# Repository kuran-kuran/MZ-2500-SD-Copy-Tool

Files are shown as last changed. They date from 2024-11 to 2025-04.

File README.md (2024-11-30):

# SHARP MZ-2500 SD Copy Tool

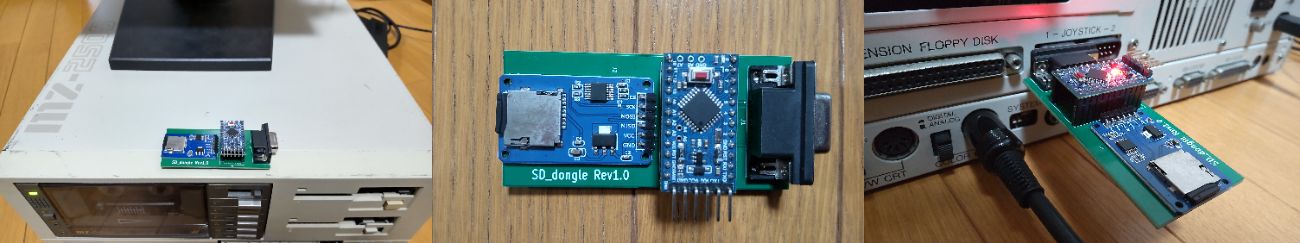
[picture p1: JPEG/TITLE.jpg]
MZ-2500 SD Copy Tool


　MZ-2500のジョイスティックポート1に挿したSD-dongleのSD-CARDとMZ-2500のFD、HDD間でOBT、BTX、BSDファイルを相互にコピーできるツールです。

　Windows等のツールで作成したMZ-2500用の機械語及びBASICプログラムをMZ-2500のFD、HDDにコピー、MZ-2500のFD、HDDのファイルを取り出してWindows等のツールで修正し、MZ-2500のFD、HDDに戻す等が簡単にできます。

## 回路図
　KiCadフォルダ内のSD_dongle.pdfを参照してください。

[回路図](https://github.com/yanataka60/MZ-2500-SD-Copy-Tool/blob/main/Kicad/SD_dongle.pdf)

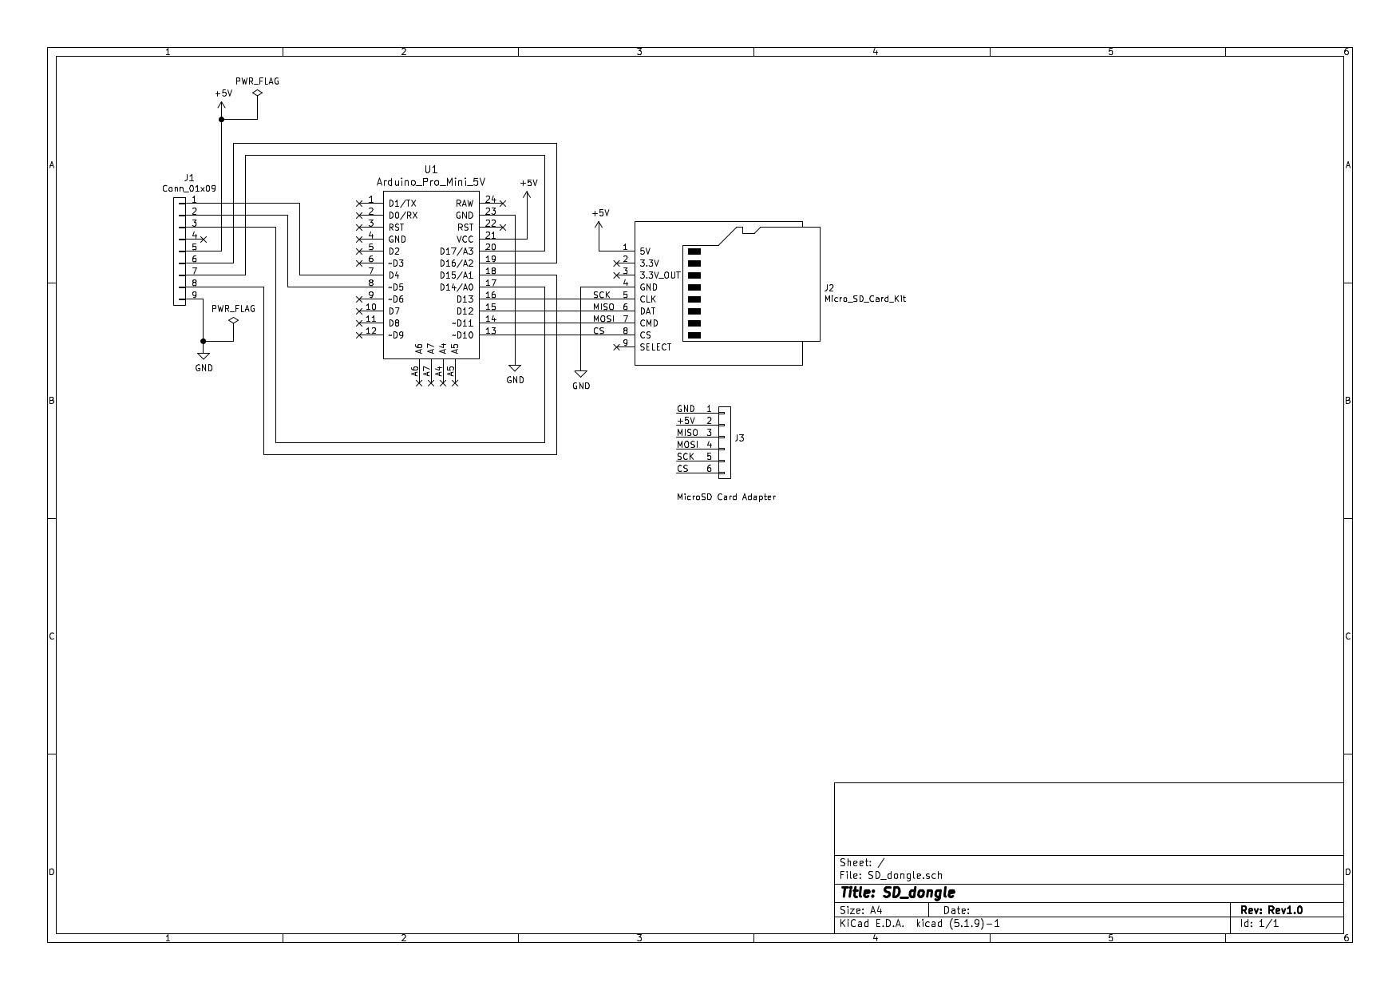
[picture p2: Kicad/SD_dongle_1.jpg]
SD_dongle


|番号|品名|数量|備考|
| --- | --- | --- | --- |
|J1|D-SUBコネクター9Pメス|1|マルツ 3223DB9RS1S2等|
||J2、J3のいずれか|||
|J2|Micro_SD_Card_Kit|1|秋月電子通商 AE-microSD-LLCNV (注1)|
|J3|MicroSD Card Adapter|1|Arduino等に使われる5V電源に対応したもの(注2)|
|U1|Arduino_Pro_Mini_5V|1|Atmega328版を使用 168版は不可。(注3)|
||ピンソケット(任意)|12Pin×2|Arduino_Pro_Miniを取り外し可能としたい場合に調達します 秋月電子通商 FHU-1x42SGなど|

### 注1)秋月電子通商　AE-microSD-LLCNVのJ1ジャンパはショートしてください。

### 注2)MicroSD Card Adapterを使う場合

J3に取り付けます。

MicroSD Card Adapterについているピンヘッダを除去してハンダ付けするのが一番確実ですが、J2の穴にMicroSD Card Adapterをぴったりと押しつけ、裏から多めにハンダを流し込むことでハンダ付けをする方法もあります。なお、この方法の時にはしっかりハンダ付けが出来たかテスターで導通を確認しておいた方が安心です。

ハンダ付けに自信のない方はJ1の秋月電子通商　AE-microSD-LLCNVをお使いください。AE-microSD-LLCNVならパワーLED、アクセスLEDが付いています。

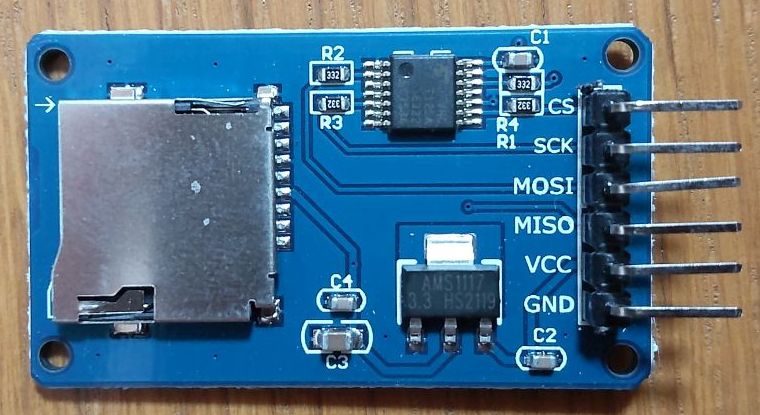
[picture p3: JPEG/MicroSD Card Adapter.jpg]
MicroSD Card Adapter1


### 注3)MZ-2500 SD Copy Tool用SD-DongleではArduino Pro MiniのA4、A5ピンは使用しません。

## Arduinoへの書込み
　Arduino IDEを使ってArduinoフォルダSD_dongleフォルダ内SD_dongle.inoを書き込みます。

　SdFatライブラリを使用しているのでArduino IDEメニューのライブラリの管理からライブラリマネージャを立ち上げて「SdFat」をインストールしてください。

　「SdFat」で検索すれば見つかります。「SdFat」と「SdFat - Adafruit Fork」が見つかりますが「SdFat」のほうを使っています。

## MZ-2500用Copy Toolプログラム
　MZ-2500のFD、HDD、FDDエミュレータ用FDイメージにOBTファイルを転送する手段がある方はSD_TRANSフォルダ内のSD_TRANS.binを転送してください。

　転送する手段の無い方はBASIC-S25又はBASIC-M25からモニタMコマンドでSD_LOADERフォルダ内のSD_LOADER.binの内容を入力します。

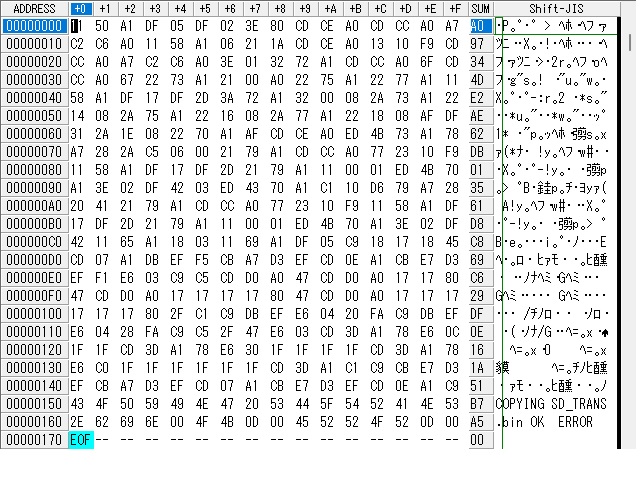
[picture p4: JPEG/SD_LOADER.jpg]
SD_LOADER


　入力間違いが無いことを確認し、SコマンドでSD_LOADER.bin等の名前を付けてセーブしてください。

　　*S A000 A16F A000:SD_LOADER.bin

　次にSD_TRANSフォルダ内のSD_TRANS.binをSD-CARDにコピーし、次のコマンドを実行します。

### (BASIC-M25)

　clear &HA000

　bload "SD_LOADER.bin"

　FD、HDDのカレントディレクトリをSD_TRANS.bin転送先ディレクトリに変更

　call &HA000

### (BASIC-S25)

　limit &HA000

　load "SD_LOADER.bin"

　FD、HDDのカレントディレクトリをSD_TRANS.bin転送先ディレクトリに変更

　call &HA000

　問題が無ければ「OK」と表示されて終了し、SD_TRANS.binがFD、HDDのカレントディレクトリに転送されているはずです。

## SD-CARD
　出来れば8GB以下のSDカードを用意してください。

　ArduinoのSdFatライブラリは、SD規格(最大2GB)、SDHC規格(2GB～32GB)に対応していますが、SDXC規格(32GB～2TB)には対応していません。

　また、SDHC規格のSDカードであっても32GB、16GBは相性により動作しないものがあるようです。

　FAT16又はFAT32が認識できます。NTFSは認識できません。

## 操作方法
　clear又はlimitで機械語領域を確保してからbload又はloadコマンドでSD_TRANS.binをロードします。

　必要があればFD又はHDDのカレントディレクトリを変更しておきます。

　SD-Dongleをジョイスティックポート1に挿します。

　call &HA000でCopy Toolを実行します。

　SD-CARDのファイル名は拡張子も含めて32文字まで、ただし漢字、半角カタカナ、及び一部の記号はArduinoが認識しないので使えません。パソコンでファイル名を付けるときはアルファベット、数字および空白でファイル名をつけてください。

　また、SD-CARDからFD、HDDにコピーされたファイルのファイル名は先頭16文字までとなります。

　Copy Toolが起動したらまず処理の選択をします。

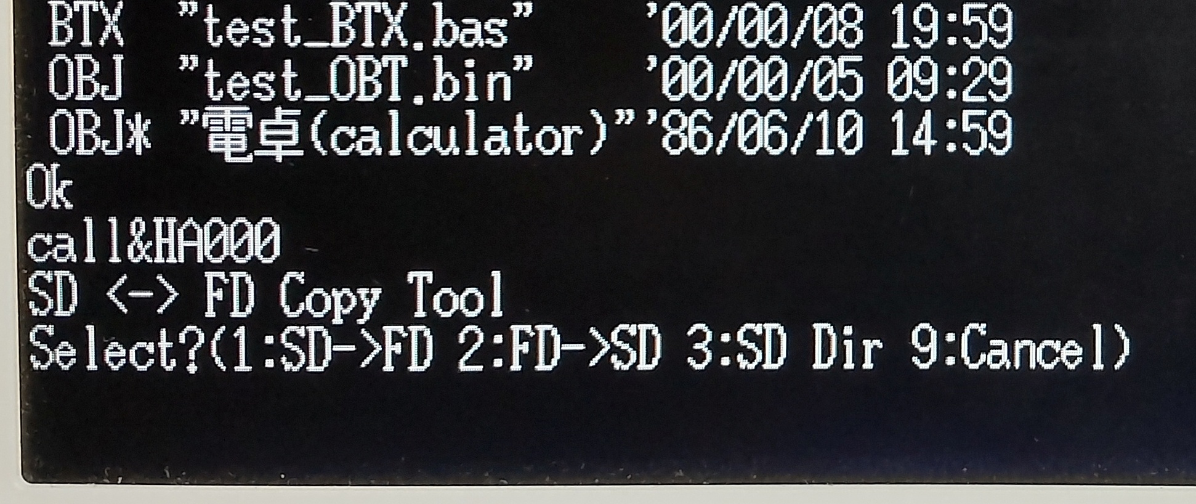
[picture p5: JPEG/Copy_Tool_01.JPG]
Copy_Tool_01


### 1 SD -> FD
　SD-CARDのファイルをFD、HDDにコピーします。

　次にSD-CARDのファイル名を指定します。

　大文字、小文字は区別されるので大文字、小文字も正確に入力してください。

　FD、HDDにはSD-CARDのファイル名のままコピーされますが、16文字を超えた分は切り捨てられます。

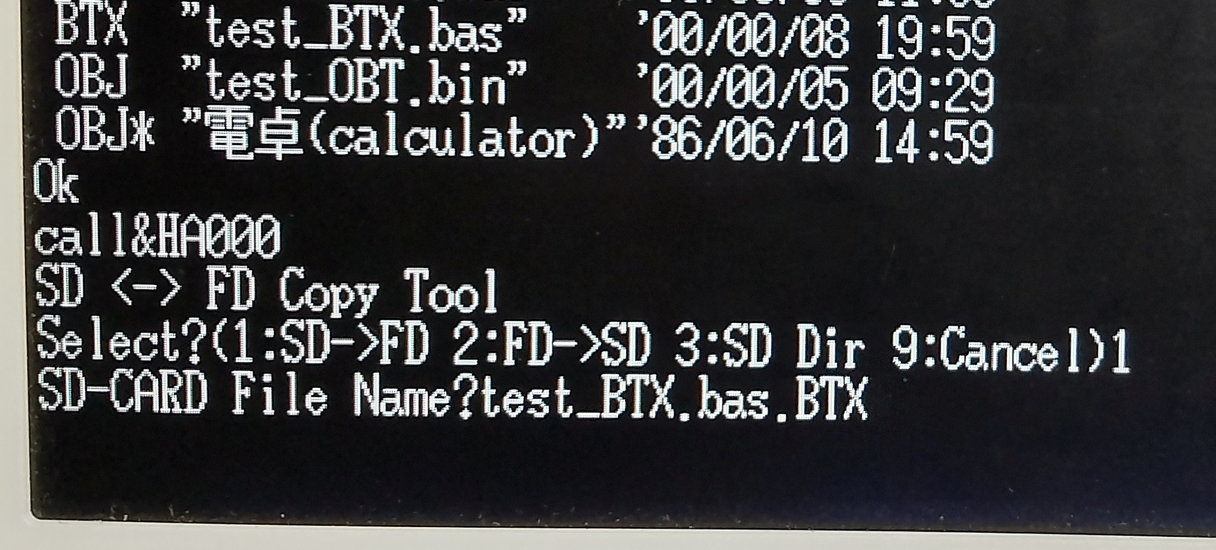
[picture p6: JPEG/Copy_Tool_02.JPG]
Copy_Tool_02


　ファイルモードを指定します。SD-CARDのファイルにはファイルモード等の情報が含まれていないため指定する必要があります。

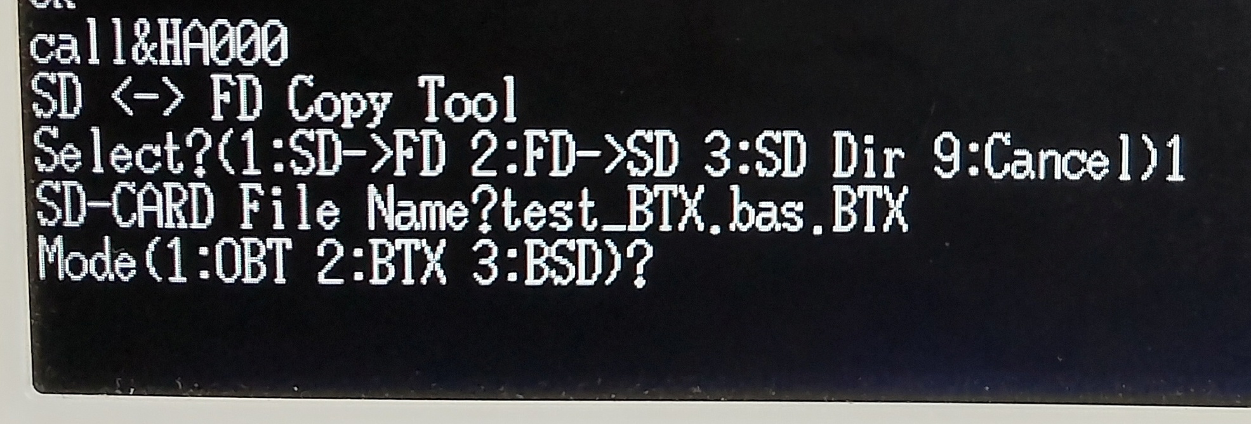
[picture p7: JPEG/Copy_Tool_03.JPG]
Copy_Tool_03


　実際のファイルモードと指定したファイルモードが間違っていてもコピーは正常終了しますが、MZ-2500のBASICからは期待した動作が出来なくなりますので削除してください。

#### 1 OBT
　SD-CARDのファイルには先頭アドレス、実行アドレスの情報が含まれていないため指定する必要があります。

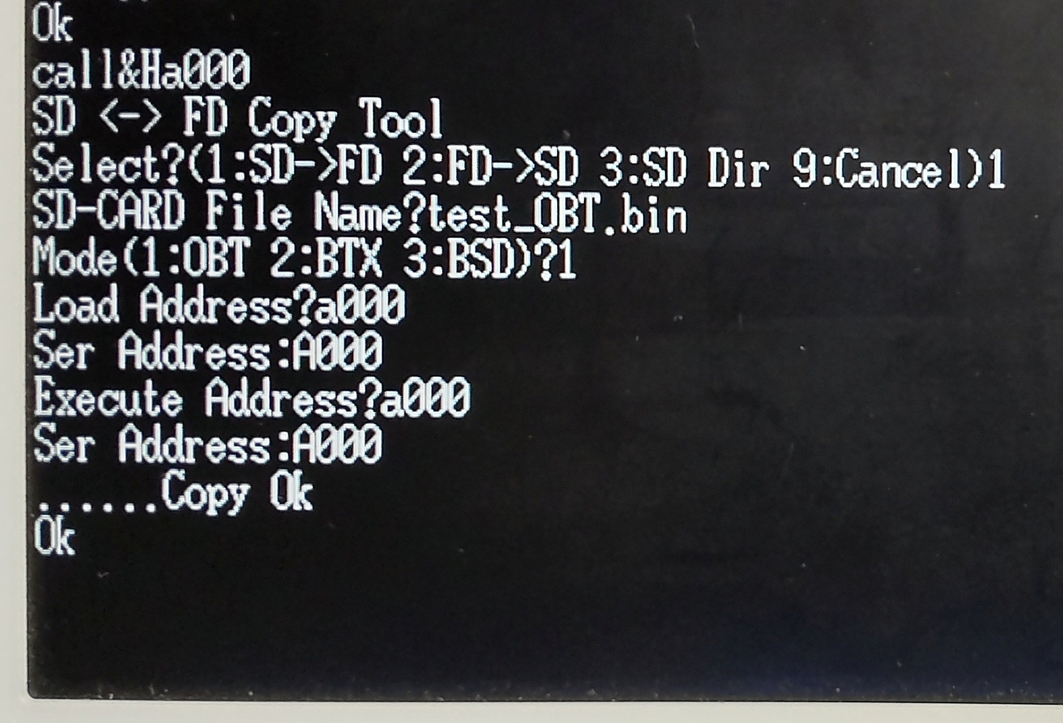
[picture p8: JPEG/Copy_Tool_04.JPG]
Copy_Tool_04


#### 2 BXT
　ファイルモードを指定するだけでコピーが始まります。

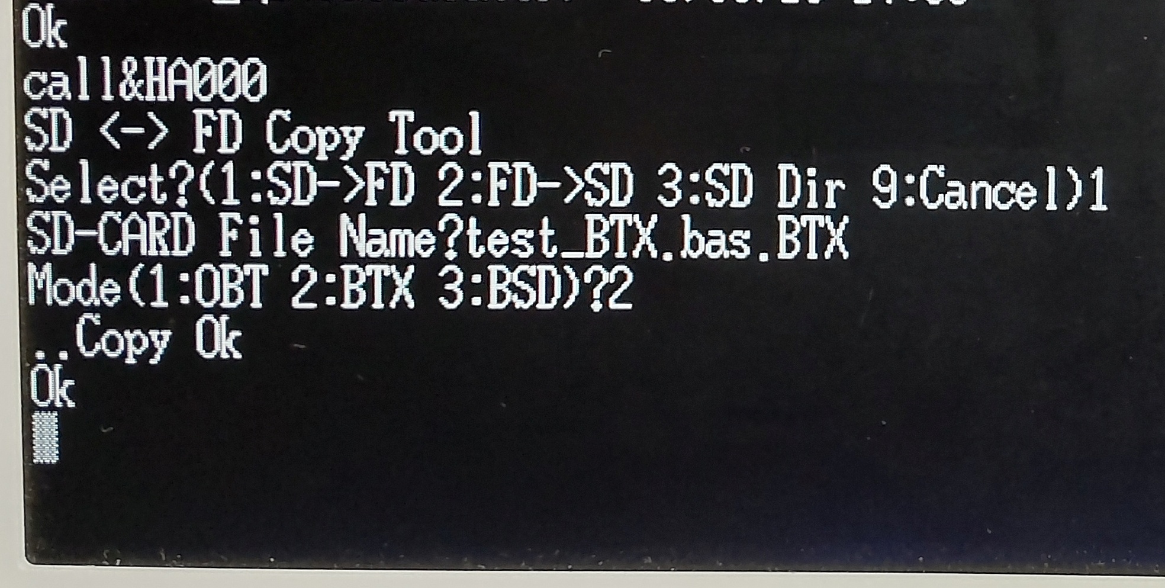
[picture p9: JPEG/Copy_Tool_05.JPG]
Copy_Tool_05


#### 3 BSD
　ファイルモードを指定するだけでコピーが始まります。

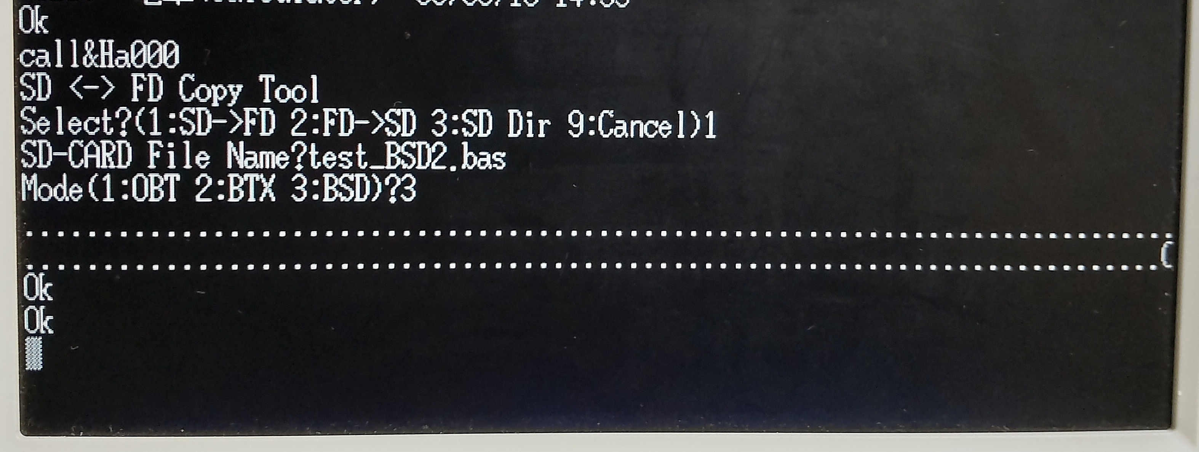
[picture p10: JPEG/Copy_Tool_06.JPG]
Copy_Tool_06


　BSDファイルとはテキストファイルであり、Windows等のテキストエディタでBASICのプログラムとして入力することも可能です。

　ただし、改行コードは0Dhのみ(Windowsのテキストの改行コードは通常0Dh,0Ah)、漢字コードはSHIFTJISで作成してください。

## 注意!!
　SD-CARDからコピーされるファイル名のファイルがコピー先のFD、HDD上に既にある場合、エラー終了します。

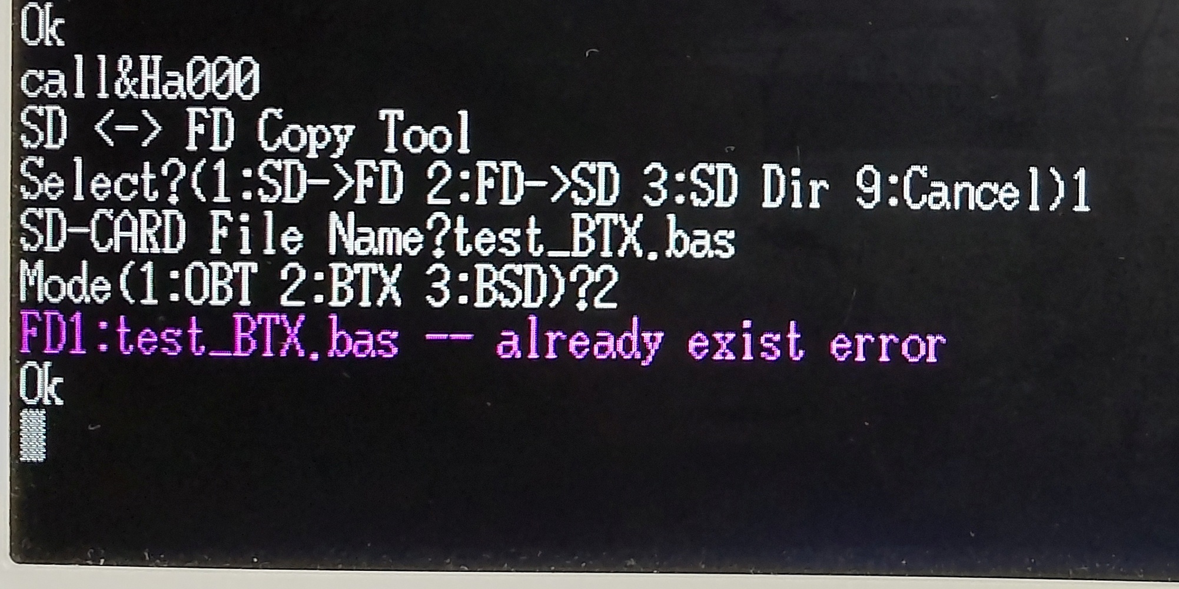
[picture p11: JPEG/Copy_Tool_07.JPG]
Copy_Tool_07


　この「already exist error」で中止されたことをArduinoは認識できないため転送処理が中途半端なまま待機状態となっており、次にCopy Toolが起動されても正常に処理できません。

## 　SD-Dongleを挿し直すことで正常に処理できるよう復旧するので、もう一度Copy Toolを起動する前に必ずSD-Dongleを挿し直してください。

　FD、HDD上に既にあるファイルもCopy Tool起動前には削除してください。

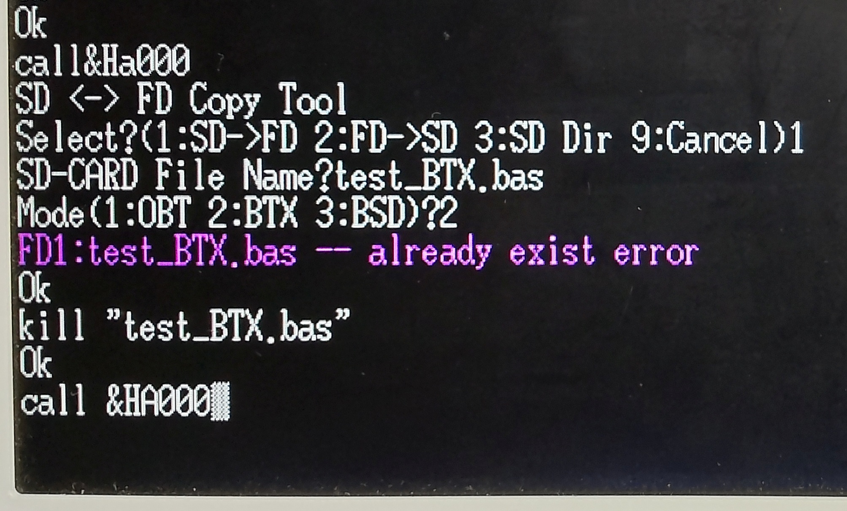
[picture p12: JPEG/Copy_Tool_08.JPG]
Copy_Tool_08


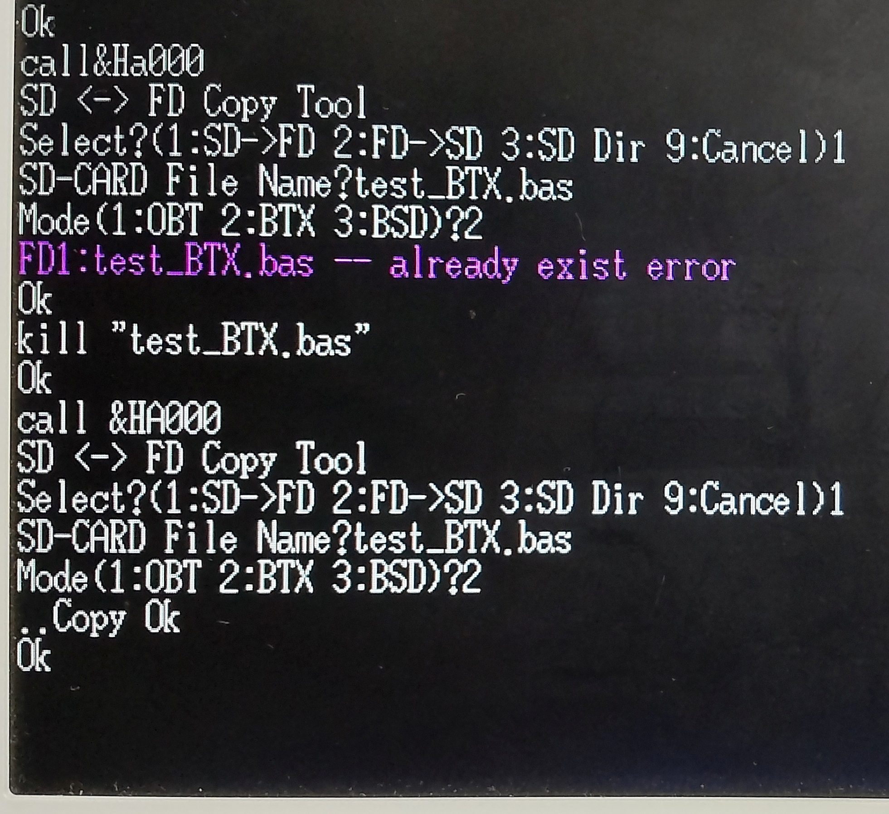
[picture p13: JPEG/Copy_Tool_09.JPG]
Copy_Tool_09


### 2 FD -> SD
　FD、HDDのファイルをSD-CARDにコピーします。

　FD、HDDのファイル名を指定します。

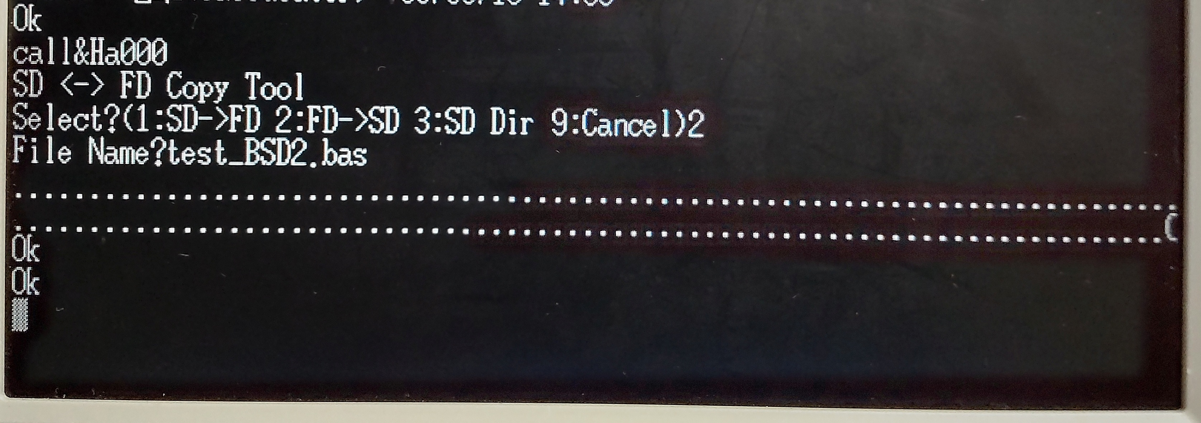
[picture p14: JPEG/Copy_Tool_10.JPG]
Copy_Tool_10


　SD-CARDにコピーされるファイルのファイル名にはFD、HDD上のファイル情報に基づき、拡張子及び先頭アドレス、実行アドレスが付加されます。

　　[OBTファイル] test.OBJ -> test.OBJ_A000_A000.OBT

　　[BTXファイル] test.m25 -> test.m25.BTX

　　[BSDファイル] test     -> test.BSD

### 3 SD DIR
　SD-CARDのルートディレクトリにあるファイル一覧からファイルを選択することでSD-CARDのファイルをFD、HDDにコピーできます。

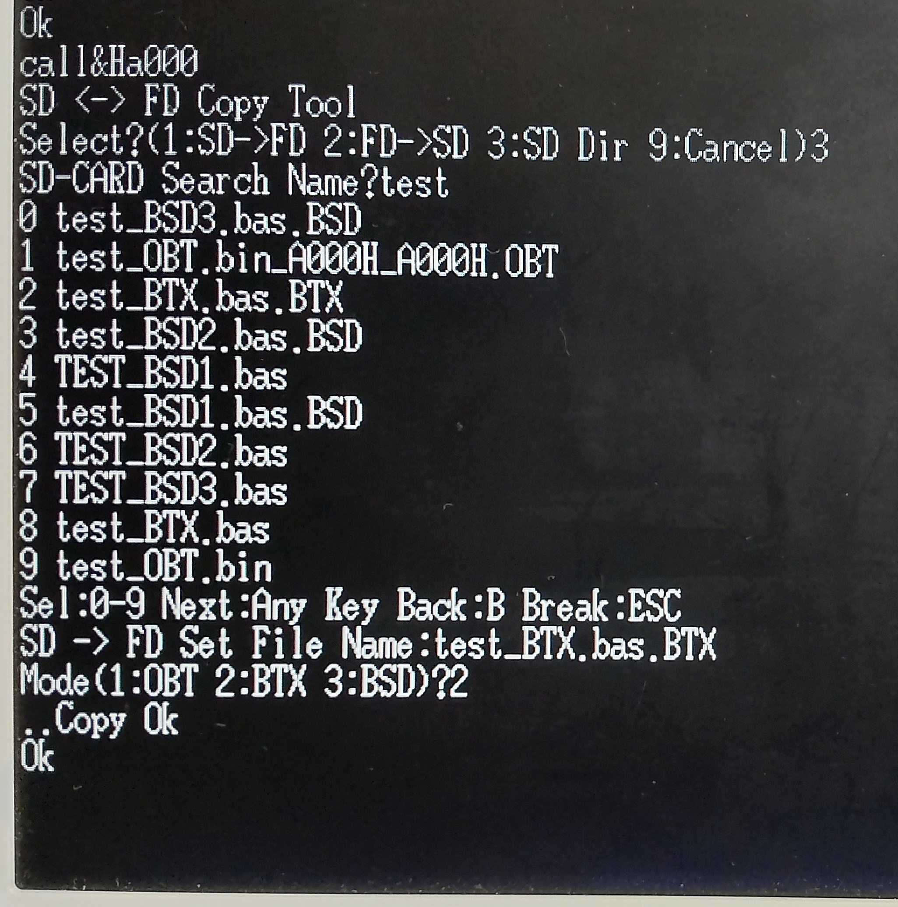
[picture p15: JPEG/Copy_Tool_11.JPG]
Copy_Tool_11


　「SD-CARD Search Name?」と聞いてくるので文字列を何も指定せずにENTERキーのみとするとSD-CARDルートディレクトリにあるファイルの一覧を表示します。

　文字列を指定するとSD-CARDルートディレクトリにあるその文字列から始まるファイルの一覧を表示します。

　10件表示したところで指示待ちになるので打ち切るならESCキー、Bキーで前の10件に戻ります。それ以外のキーで次の10件を表示します。

　行頭に0から9の数字を付加して表示してあるのでコピーしたいファイルの頭についている数字を入力するとコピー処理に移行します。

　検索する文字列は大文字、小文字の区別はありません。大文字、小文字のどちらで入力しても大丈夫です。

　表示される順番は、登録順となりファイル名アルファベッド順などのソートした順で表示することはできません。

## 追記
2024.11.30　Arduinoプログラムに安定性の向上を追加

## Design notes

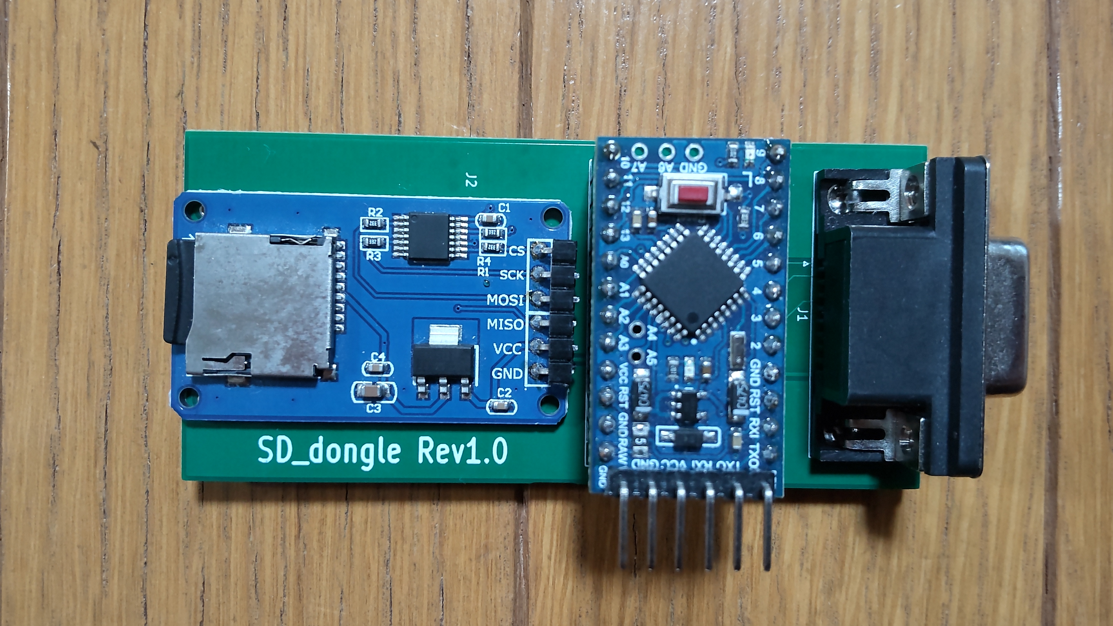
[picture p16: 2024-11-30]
JPEG/SD_dongle.JPG

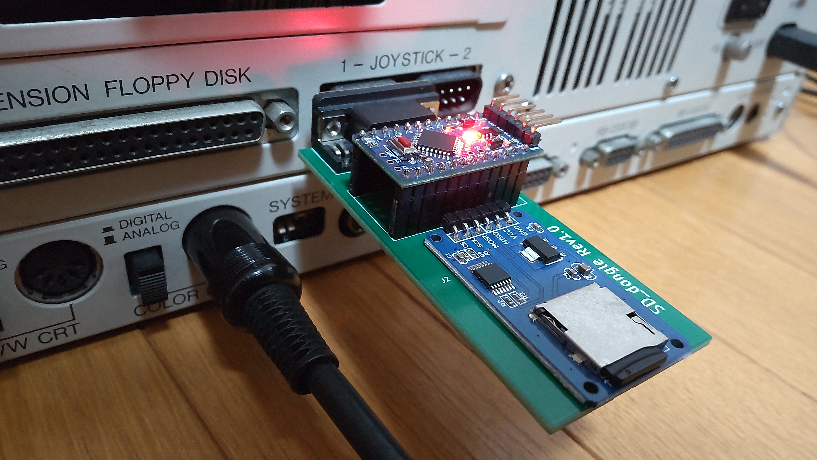
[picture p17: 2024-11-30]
JPEG/MZ-2500(2).JPG

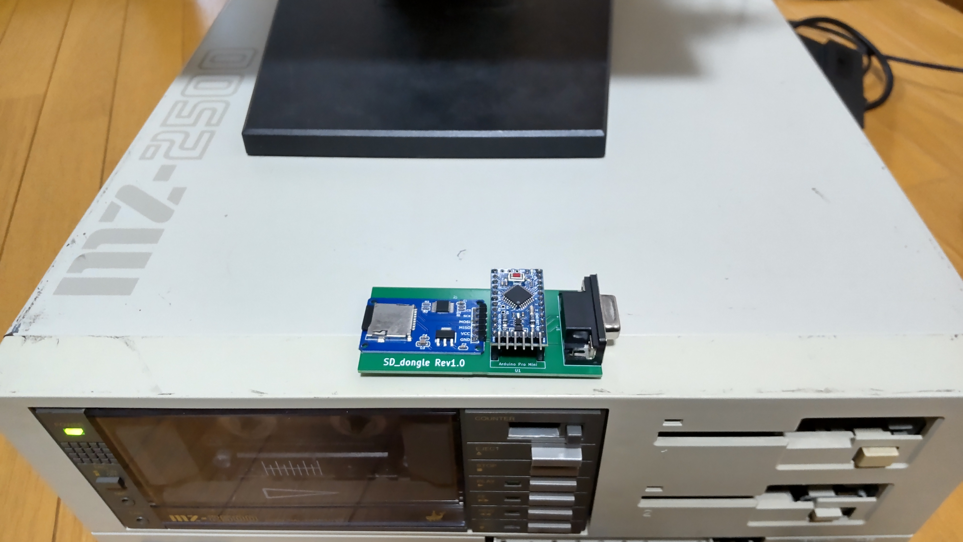
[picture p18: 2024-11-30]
JPEG/MZ-2500(1).JPG

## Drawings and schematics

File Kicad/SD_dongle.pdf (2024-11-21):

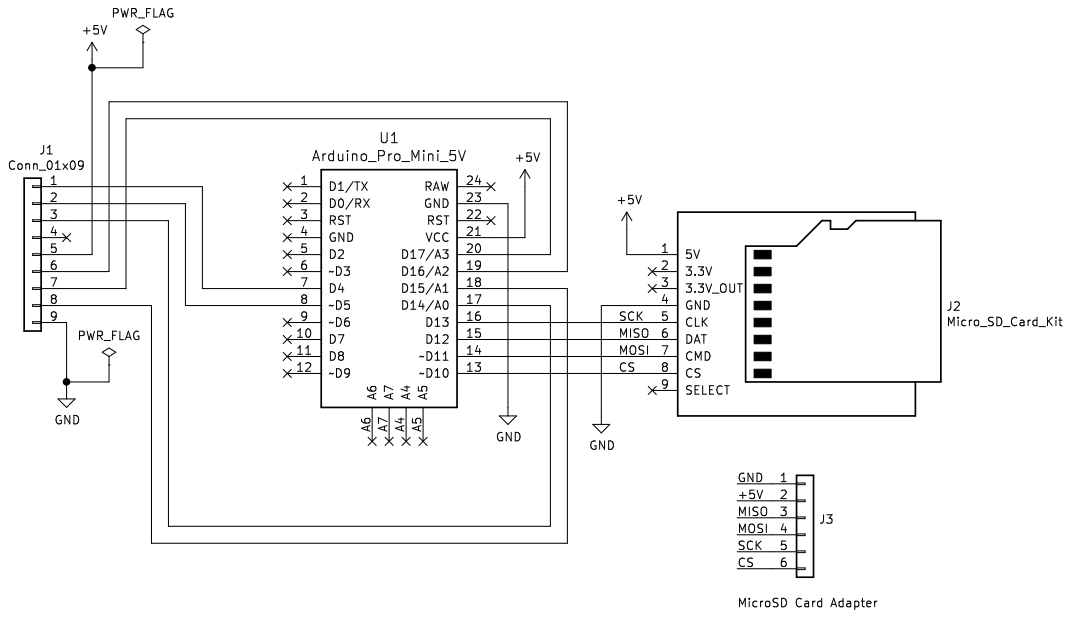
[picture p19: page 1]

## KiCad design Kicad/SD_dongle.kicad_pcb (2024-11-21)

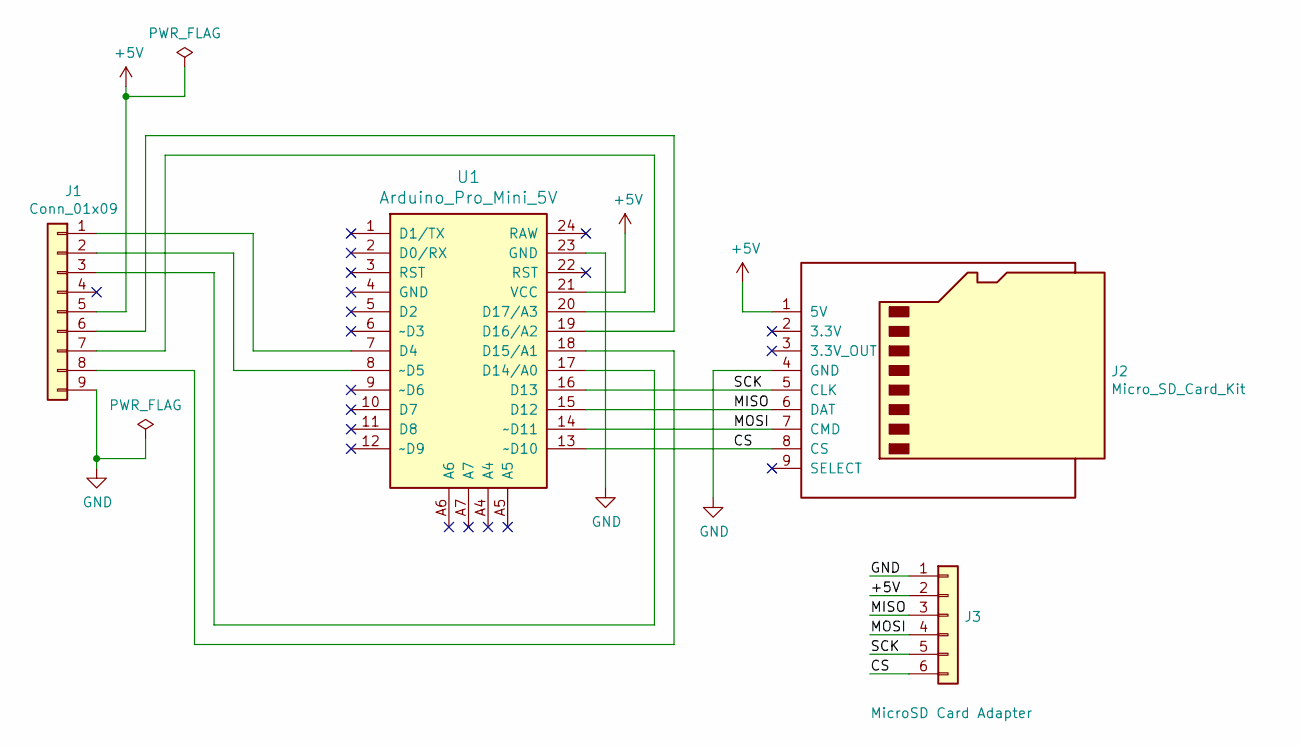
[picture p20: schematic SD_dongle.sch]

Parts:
J1: Conn_01x09; DSUB-9_Female_Horizontal_P2.77x2.84mm_EdgePinOffset7.70mm_H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
J2: Micro_SD_Card_Kit; AE-microSD-LLCNV
J3: MicroSD Card Adapter; PinSocket_1x06_P2.54mm_Vertical
U1: Arduino_Pro_Mini_5V; Arduino_Pro_Mini

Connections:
+5V: J1.5, J2.1 (5V), J3.2, U1.21 (VCC)
/CS: J2.8 (CS), J3.6, U1.13 (~~D10)
/MISO: J2.6 (DAT), J3.3, U1.15 (D12)
/MOSI: J2.7 (CMD), J3.4, U1.14 (~~D11)
/SCK: J2.5 (CLK), J3.5, U1.16 (D13)
GND: J1.9, J2.4 (GND), J3.1, U1.23 (GND)
unnamed: J1.1, U1.7 (D4)
unnamed: J1.2, U1.8 (~~D5)
unnamed: J1.3, U1.17 (D14/A0)
unnamed: J1.6, U1.19 (D16/A2)
unnamed: J1.7, U1.20 (D17/A3)
unnamed: J1.8, U1.18 (D15/A1)

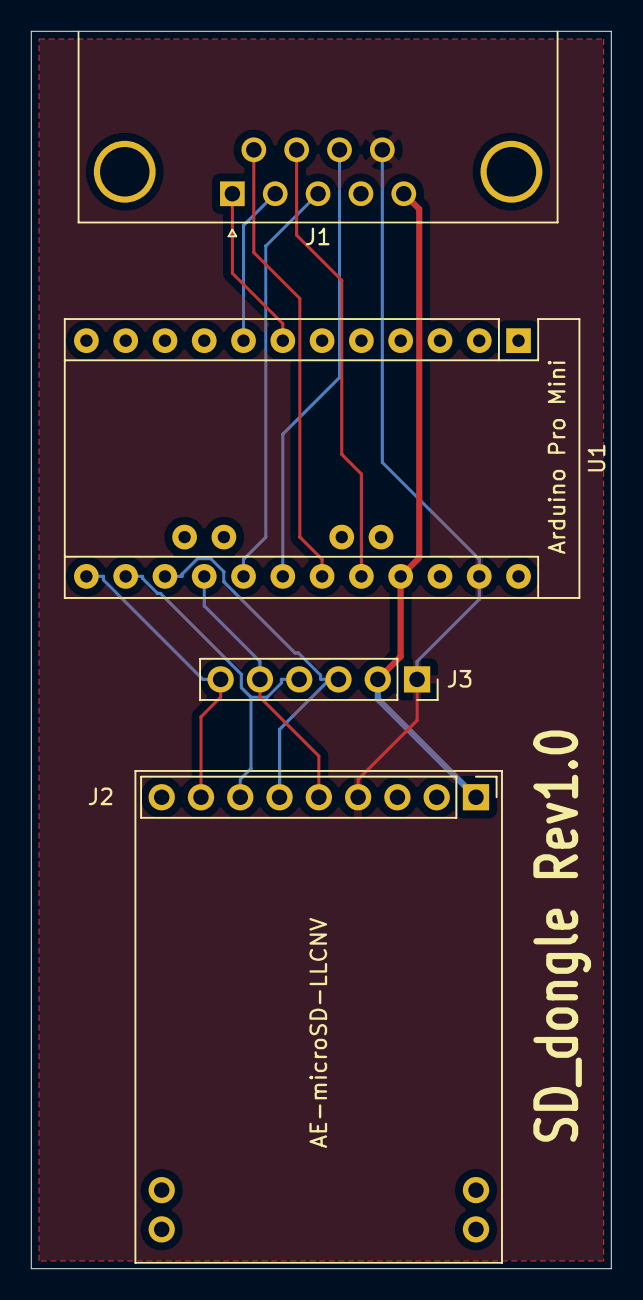
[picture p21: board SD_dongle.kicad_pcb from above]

Board: 2 copper layers, 37.5 x 80.0 mm, 4 parts (0 on the bottom side), 12 nets.

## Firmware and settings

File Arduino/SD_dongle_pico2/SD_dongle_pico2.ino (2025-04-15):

// 2024.11.30 INPUT_PULLUPに修正
// 2024.12.24 RaspberryPI Picoでビルドできるようにした
// 2025.04.16 RaspberryPI Pico2でビルドできるようにした
//
// Joypad  Arduino       Pico
// 1 ----- 4(PB2)  ----- 1
// 2 ----- 5(PB3)  ----- 2
// 3 ----- 14(GLG) ----- 3
// 4 ----- NC      ----- NC
// 5 ----- +5V     ----- VBUS
// 6 ----- 16(PA0) ----- 4
// 7 ----- 17(PA1) ----- 5
// 8 ----- 15(CHK) ----- 0
// 9 ----- GND     ----- GND
//
#include <SPI.h>
#include <SD.h>
//SdFat SD;
char f_name[40];
char c_name[40];
char buf1[10],buf2[10];
char sdir[10][40];
File file;
unsigned long f_length,f_length2,f_length1;
#define CABLESELECTPIN  (17)
#define CHKPIN          (0)
#define PB2PIN          (1)
#define PB3PIN          (2)
#define FLGPIN          (3)
#define PA0PIN          (4)
#define PA1PIN          (5)
// ファイル名は、ロングファイルネーム形式対応
boolean eflg;

void sdinit(void){
  // SD初期化
  if( !SD.begin(CABLESELECTPIN,8) )
  {
////    Serial.println("Failed : SD.begin");
    eflg = true;
  } else {
////    Serial.println("OK : SD.begin");
    eflg = false;
  }
////    Serial.println("START");
}

void setup(){
////  Serial.begin(9600);
// CS=pin10
// pin10 output

  pinMode(CABLESELECTPIN,OUTPUT);
  pinMode( CHKPIN,INPUT);  //CHK
  pinMode( PB2PIN,OUTPUT); //送信データ
  pinMode( PB3PIN,OUTPUT); //送信データ
  pinMode( FLGPIN,OUTPUT); //FLG

  pinMode( PA0PIN,INPUT_PULLUP); //受信データ
  pinMode( PA1PIN,INPUT_PULLUP); //受信データ

  pinMode(LED_BUILTIN, OUTPUT);
  digitalWrite(LED_BUILTIN, HIGH); // LED点灯

  digitalWrite(PB2PIN,LOW);
  digitalWrite(PB3PIN,LOW);
  digitalWrite(FLGPIN,LOW);

  sdinit();
}

//2BIT受信
byte rcv2bit(void){
//LOWになるまでループ
  while(digitalRead(CHKPIN) != LOW){
  }
//受信
  byte j_data = digitalRead(PA0PIN)+digitalRead(PA1PIN)*2;
//FLGをセット
  digitalWrite(FLGPIN,LOW);
//HIGHになるまでループ
  while(digitalRead(CHKPIN) == LOW){
  }
//FLGをリセット
  digitalWrite(FLGPIN,HIGH);
  return(j_data);
}

//1BYTE受信
byte rcv1byte(void){
  byte i_data = 0;
  i_data=rcv2bit();
  i_data=i_data+rcv2bit()*4;
  i_data=i_data+rcv2bit()*16;
  i_data=i_data+rcv2bit()*64;
  return(~i_data);
}

//2BIT送信
void snd2bit(byte j_data)
{
  digitalWrite(PB2PIN,(j_data)&0x01);
  digitalWrite(PB3PIN,(j_data>>1)&0x01);
//FLGをセット
  digitalWrite(FLGPIN,LOW);
//LOWになるまでループ
  while(digitalRead(CHKPIN) != LOW){
  }
  digitalWrite(FLGPIN,HIGH);
//HIGHになるまでループ
  while(digitalRead(CHKPIN) == LOW){
  }
//FLGをリセット
  digitalWrite(FLGPIN,HIGH);
}

//1BYTE送信
void snd1byte(byte i_data){
  snd2bit((~i_data)&0x03);
  snd2bit((~i_data>>2)&0x03);
  snd2bit((~i_data>>4)&0x03);
  snd2bit((~i_data>>6)&0x03);
}

//SDカードから読込
void f_load(void){
  int wk1 = 0;
  unsigned int lp1;
//ファイルネーム取得
  receive_name(f_name);
//ファイルが存在しなければERROR
  if (SD.exists(f_name) == true){
//ファイルオープン
    file = SD.open( f_name, FILE_READ );
    if( true == file ){
//状態コード送信(OK)
        snd1byte(0x00);

//ファイルサイズ取得
        f_length = file.size();
        f_length2 = f_length % 256;
        f_length1 = f_length / 256;
        snd1byte(f_length2);
        snd1byte(f_length1);

        if(rcv1byte()==0x00){
//データ送信
          if(f_length>0){
            for (lp1 = 1;lp1 <= f_length;lp1++){
              wk1 = file.read();
              snd1byte(wk1);
            }
          }
        }
        file.close();
        sdinit();
     } else {
//状態コード送信(ERROR)
      snd1byte(0xFF);
      sdinit();
     }
   } else {
//状態コード送信(FILE NOT FIND ERROR)
    snd1byte(0xF1);
    sdinit();
  }
}

//SDカードに書き込み
void f_save(void){
  byte wk1 = 0;
  unsigned long lp1,fmode,s_adrs,s_adrs1,s_adrs2,g_adrs,g_adrs1,g_adrs2;
  String buf11,buf22;
//ファイルネーム取得
  receive_name(f_name);

//ファイルタイプ取得
  fmode = rcv1byte();
//ファイルサイズ取得
  f_length1 = rcv1byte();
  f_length2 = rcv1byte();
//ファイルサイズ算出
  f_length = f_length1*256+f_length2;
//スタートアドレス取得
  s_adrs1 = rcv1byte();
  s_adrs2 = rcv1byte();
//スタートアドレス算出
  s_adrs = s_adrs1*256+s_adrs2;
//実行アドレス取得
  g_adrs1 = rcv1byte();
  g_adrs2 = rcv1byte();
//実行アドレス算出
  g_adrs = g_adrs1*256+g_adrs2;
  String fname = f_name;

//fmodeによりファイル名修正
  switch(fmode){
    case 1:
      sprintf(buf1,"%04x",s_adrs);
      buf11 = buf1;
      buf11.toUpperCase();
      sprintf(buf2,"%04x",g_adrs);
      buf22 = buf2;
      buf22.toUpperCase();
      fname = fname + "_"+buf11+"H_"+buf22+"H.OBT";
      break;
    case 2:
      fname = fname + ".BTX";
      break;
    case 3:
      fname = fname + ".BSD";
      break;
  }

//ファイルが存在すればdelete
  if (SD.exists(fname) == true){
    SD.remove(fname);
  }
//ファイルオープン
  file = SD.open( fname, FILE_WRITE );
  if( true == file ){
//状態コード送信(OK)
    snd1byte(0x00);
    if(rcv1byte()==0x00){
      if(f_length>0){
        for (lp1 = 1;lp1 <= f_length;lp1++){
          wk1 = rcv1byte();
          file.write(wk1);
        }
      }
    }
    file.close();
  } else {
//状態コード送信(ERROR)
    snd1byte(0xFF);
    sdinit();
  }
}

//比較文字列取得 32+1文字まで取得、ただしダブルコーテーションは無視する
void receive_name(char *f_name){
char r_data;
  unsigned int lp2 = 0;
  for (unsigned int lp1 = 0;lp1 <= 32;lp1++){
    r_data = rcv1byte();
    if (r_data != 0x22){
      f_name[lp2] = r_data;
      lp2++;
    }
  }
}

//f_nameとc_nameをc_nameに0x00が出るまで比較
//FILENAME COMPARE
boolean f_match(char *f_name,char *c_name){
  boolean flg1 = true;
  unsigned int lp1 = 0;
  while (lp1 <=32 && c_name[0] != 0x00 && flg1 == true){
    if (upper(f_name[lp1]) != upper(c_name[lp1])){
      flg1 = false;
    }
    lp1++;
    if (c_name[lp1]==0x00){
      break;
    }
  }
  return flg1;
}

//小文字->大文字
char upper(char c){
  if('a' <= c && c <= 'z'){
    c = c - ('a' - 'A');
  }
  return c;
}


// SD-CARDのFILELIST
void dirlist(void){
//比較文字列取得 32+1文字まで
  receive_name(c_name);
  File file2 = SD.open( "/" );
  if( file2 == true ){
//状態コード送信(OK)
    snd1byte(0x00);

    File entry =  file2.openNextFile();
    int cntl2 = 0;
    unsigned int br_chk =0;
    int page = 1;
//全件出力の場合には10件出力したところで一時停止、キー入力により継続、打ち切りを選択
    while (br_chk == 0) {
      if(entry){
        //entry.getName(f_name,36);
        memset(f_name, 0, sizeof(f_name));
        memcpy(f_name, entry.name(), strlen(entry.name()));
        unsigned int lp1=0;
//一件送信
//比較文字列でファイルネームを先頭から比較して一致するものだけを出力
        if (f_match(f_name,c_name)){
//sdir[]にf_nameを保存
          strcpy(sdir[cntl2],f_name);
          snd1byte(0x30+cntl2);
          snd1byte(0x20);
          while (lp1<=36 && f_name[lp1]!=0x00){
            snd1byte(f_name[lp1]);
            lp1++;
          }
          snd1byte(0x00);
          cntl2++;
        }
      }
// CNTL2 > 表示件数-1
      if (!entry || cntl2 > 9){
//継続・打ち切り選択指示要求
        snd1byte(0xfe);

//選択指示受信(0:継続 B:前ページ 以外:打ち切り)
        br_chk = rcv1byte();
//前ページ処理
        if (br_chk==0x42 || br_chk==0x62){
//先頭ファイルへ
          file2.rewindDirectory();
//entry値更新
          entry =  file2.openNextFile();
//もう一度先頭ファイルへ
          file2.rewindDirectory();
          if(page <= 2){
//現在ページが1ページ又は2ページなら1ページ目に戻る処理
            page = 0;
          } else {
//現在ページが3ページ以降なら前々ページまでのファイルを読み飛ばす
            page = page -2;
            cntl2=0;
//page*表示件数
            while(cntl2 < page*10){
                entry =  file2.openNextFile();
                if (f_match(f_name,c_name)){
                  cntl2++;
                }
            }
         }
          br_chk=0;
        }
//1～0までの数字キーが押されたらsdir[]から該当するファイル名を送信
        if(br_chk>=0x30 && br_chk<=0x39){
          file = SD.open( sdir[br_chk-0x30], FILE_READ );
          if( file == true ){
            unsigned int lp2=0;
            snd1byte(0xFD);
            while (lp2<=36 && sdir[br_chk-0x30][lp2]!=0x00){
              snd1byte(sdir[br_chk-0x30][lp2]);
              lp2++;
            }
            snd1byte(0x00);
            file.close();
          }
        }
        page++;
        cntl2 = 0;
      }
//ファイルがまだあるなら次読み込み、なければ打ち切り指示
      if (entry){
        entry =  file2.openNextFile();
      }else{
        br_chk=1;
      }
    }
//処理終了指示
    snd1byte(0x00);
  }else{
    snd1byte(0xf1);
  }
}

void loop()
{
  digitalWrite(PB2PIN,LOW);
  digitalWrite(PB3PIN,LOW);
  digitalWrite(FLGPIN,LOW);
//コマンド取得待ち
////  Serial.print("cmd:");
  byte cmd = rcv1byte();
////  Serial.println(cmd,HEX);
  if (eflg == false){
    switch(cmd) {
//80hでSDカードからLoad
      case 0x80:
//状態コード送信(OK)
////  Serial.println("LOAD START");
//状態コード送信(OK)
        snd1byte(0x00);
        f_load();
        break;
//81hでSDカードにsave
      case 0x81:
//状態コード送信(OK)
////  Serial.println("SAVE START");
//状態コード送信(OK)
        snd1byte(0x00);
        f_save();
        break;
//82hでSDカードファイル一覧
      case 0x82:
//状態コード送信(OK)
////  Serial.println("SD DIR START");
//状態コード送信(OK)
        snd1byte(0x00);
        sdinit();
        dirlist();
        break;
      default:
//状態コード送信(CMD ERROR)
        snd1byte(0xF4);
    }
  } else {
//状態コード送信(ERROR)
    snd1byte(0xF0);
    sdinit();
  }
}

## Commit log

2024-12-03 SD_TOOL作成開始
2024-12-05 SD_BENCH追加
2024-12-05 SDBENCHがファイル読み込みできるようになった
2024-12-06 SD_BOOT追加
2024-12-06 起動テスト中
2025-02-13 RaspberryPI Picoでビルドできるようにした
2025-04-06 MZ-2000用ベンチマーク作成
2025-04-15 Pico2に転送してSDカードの初期化は成功している。転送は途中でフリーズ。
